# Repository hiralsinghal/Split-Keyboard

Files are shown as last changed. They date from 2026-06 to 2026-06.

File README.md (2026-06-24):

# Split-Keyboard
A split-keyboard made for ergnomic comfort. It has 42 keys, each side having 21. XIAO-nRF5280 is the MCU powering the project because of its wireless support.

## Features

- Wireless
- XIAO-nRF52840 is the MCU.
- 42 keys

## Schematic

You have draw hierarchical sheets and set the sheetname respectly whereas the sheet file should be named the same for both so that whatever symbols you place in one of them are copied into the other without you switching sheets constantly. This wouldnt impact the way footprints are imported into the PCB editor.

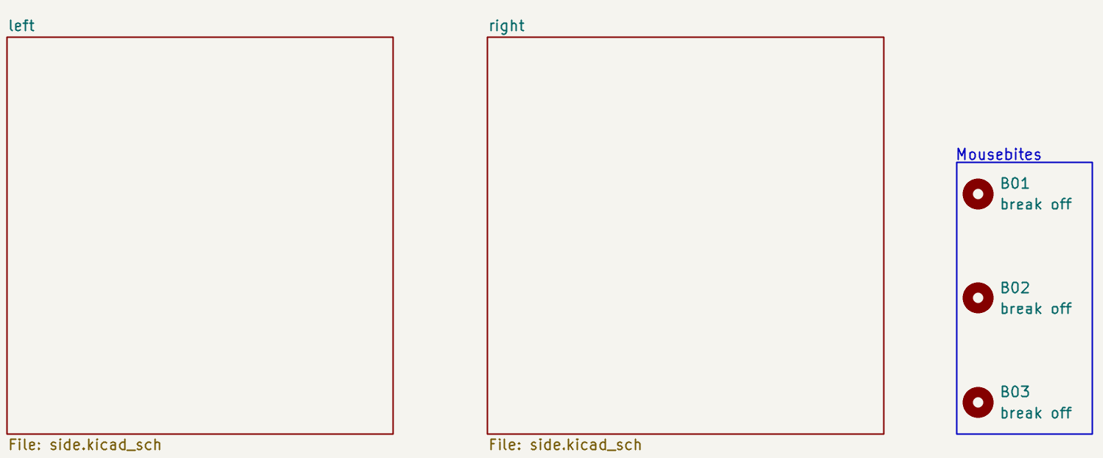
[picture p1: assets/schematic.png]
schematic


### Left Side

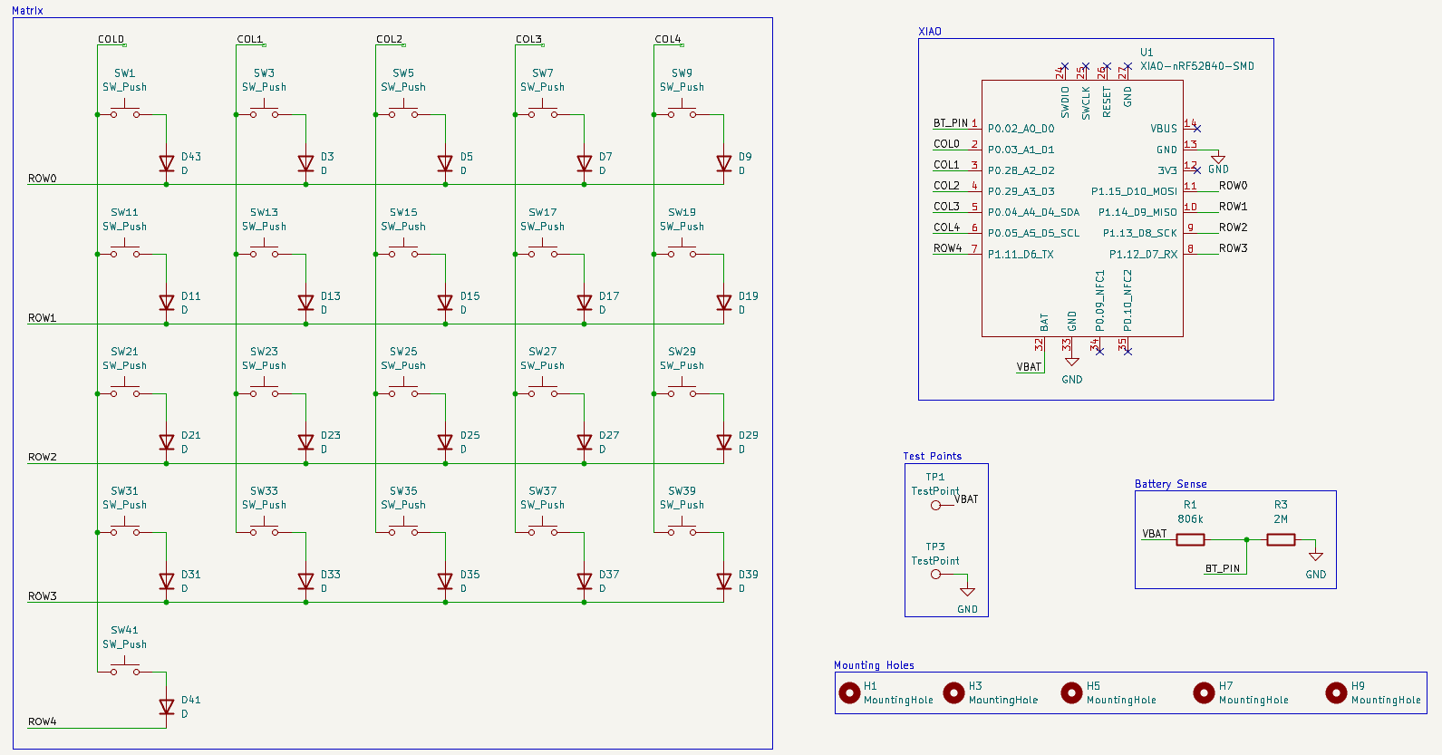
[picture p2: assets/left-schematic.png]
left side schematic


### Right Side

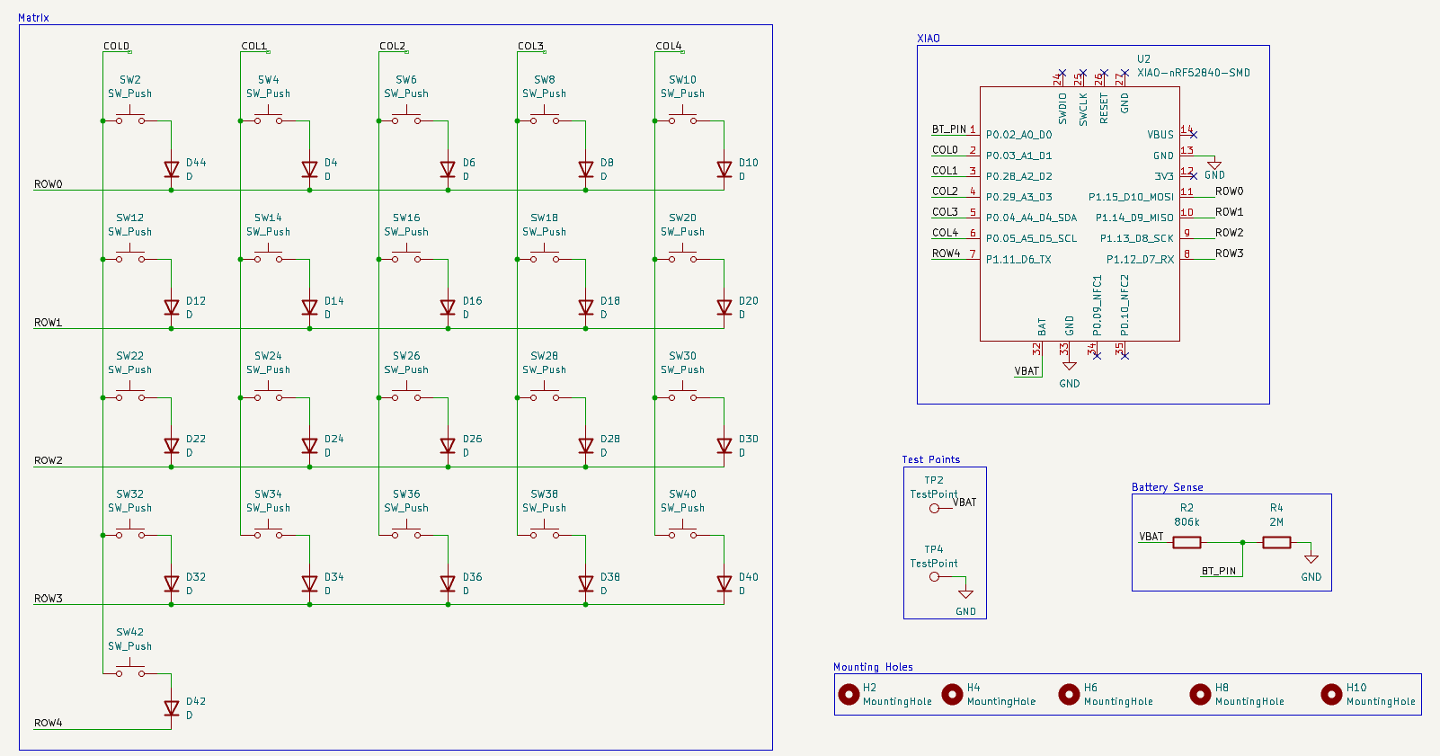
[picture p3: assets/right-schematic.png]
right side schematic


## PCB

The source files are in the PCB folder.

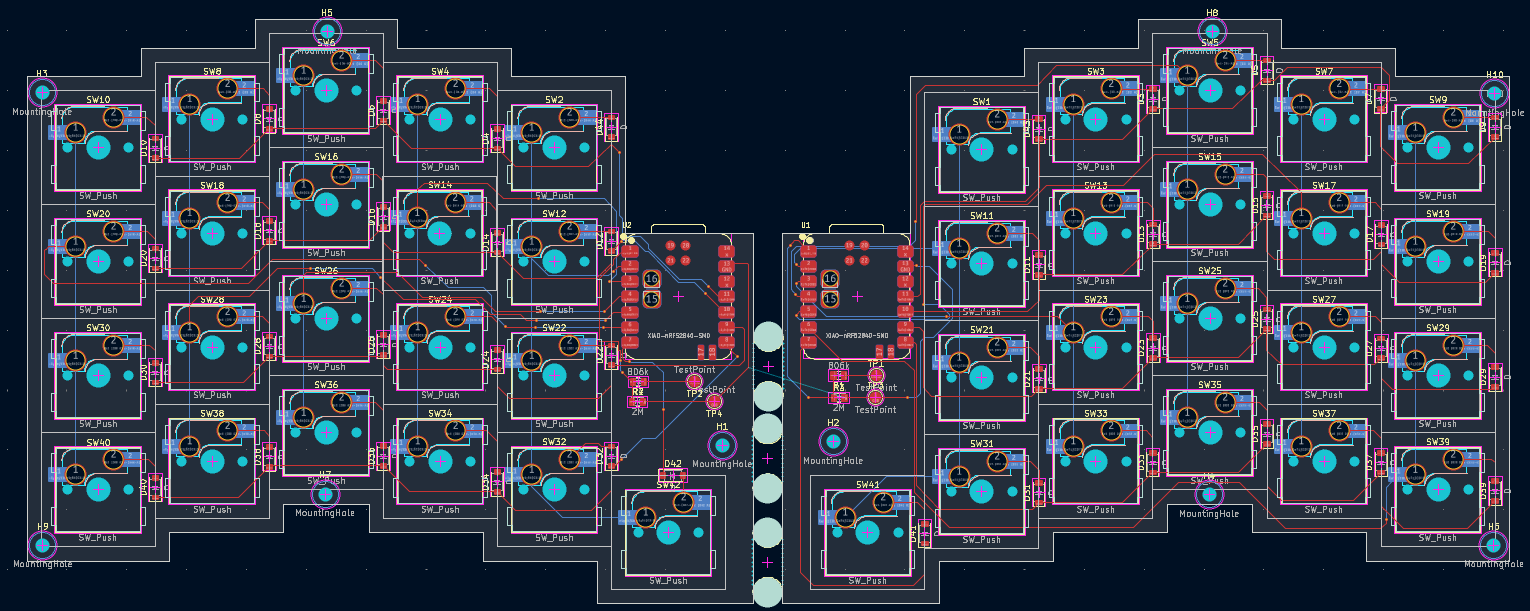
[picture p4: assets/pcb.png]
pcb


## Case

This was made in Fusion, using the PCB as reference. It has cutouts for switches, keys and XIAO ports. The source file can be found in the folder CAD.

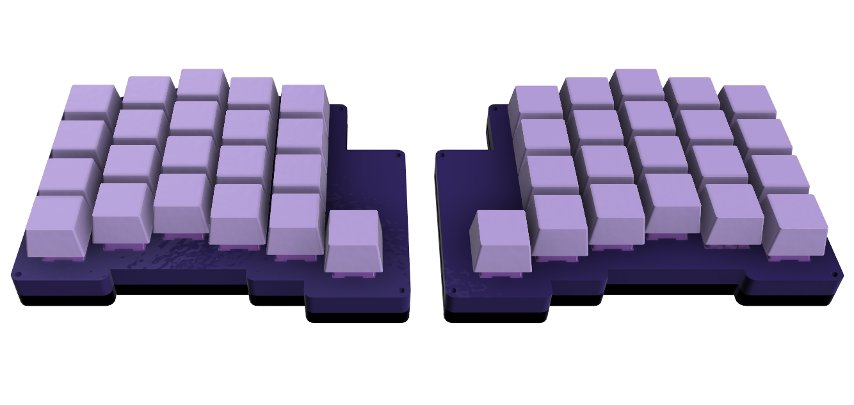
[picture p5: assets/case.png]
case


### Left

This is the case for the left side of the keyboard.

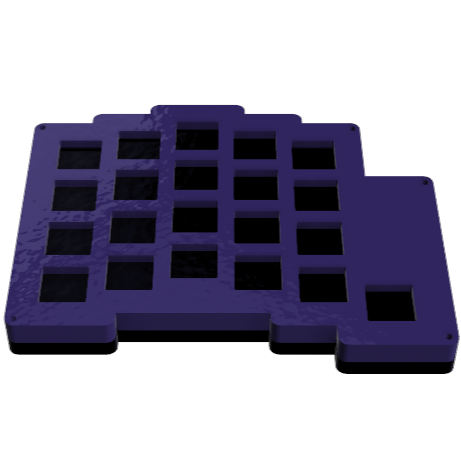
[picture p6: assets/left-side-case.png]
left-keyboard


### Right

This is the case for the right side of the keyboard.

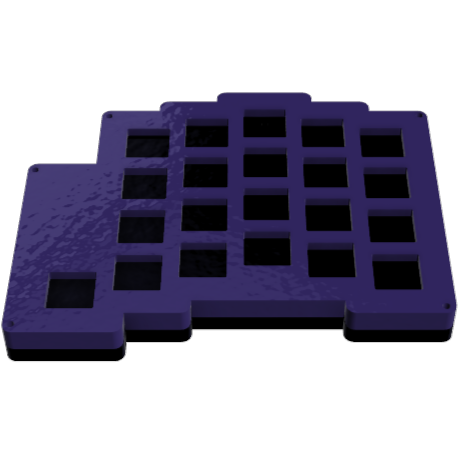
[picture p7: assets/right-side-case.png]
right-keyboard


## Firmware

It uses ZMK firmware because of its support for split keyboards. Each controller runs their own firmware but they make it work as a single device. The files are in the firmware folder.

## BOM

| Item | Description | Quantity | Unit Price ($) | Total Price ($) | URL |
| --- | --- |---| --- |--- | --- |
| PCB | PCB | 5 | 3.32 | 16.6 | |
| Seeed Studio XIAO BLE nRF52840 |MCU |2|12.2|24.4|https://robu.in/product/seeed-studio-xiao-ble-nrf52840/ |
| Akko V3 Lavender Purple Pro Switch (Pack of 45)| Keyboard Switches | 1 | 11.65 | 11.65 | https://stackskb.com/store/akko-v3-lavender-purple-pro-switch-pack-of-45/ |
| Veekos Gradient Keycaps (Cherry Profile) (135 keys)| Keycaps | 1 | 13.77 | 13.77 | https://stackskb.com/store/veekos-gradient-keycaps-cherry-profile-135-keys/?attribute_pa_colour=black |
| 1N5819 1W Diode | Diode | 42 | 0.027 | 1.13 | https://robu.in/product/1n5819-1w-diode-pack-of-30/ |
| 0805S8F1005T5E-Royal Ohm-10M 1% 0805 SMD Resistor | Resistor | 4 | 0.0086 | 0.034 | https://robu.in/product/0805s8f1005t5e-royal-ohm-10m-1-0805-smd-resistor/
| Total | | | |67.584| |

## Zine

This was made in Figma. I enjoyed making it kinda.

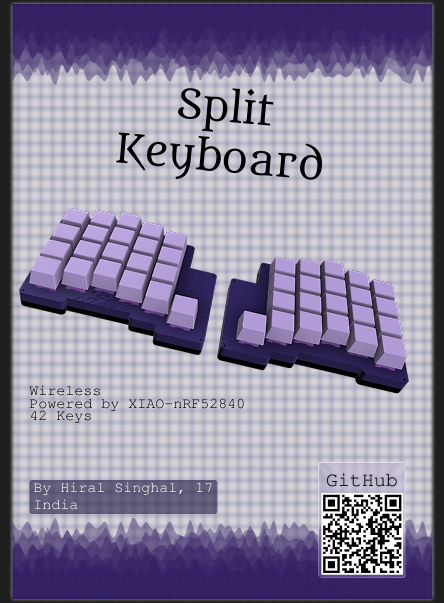
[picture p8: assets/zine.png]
zine


## Why did I make it?

I made it cause it seemed like a cool project. The routing was tough ngl. Each footprint alligned differently and so many switches and diodes. Its like each project is improving my skills consistently. I now know how to route better (kinda) This was made for [Fallout](fallout.hackclub.com).

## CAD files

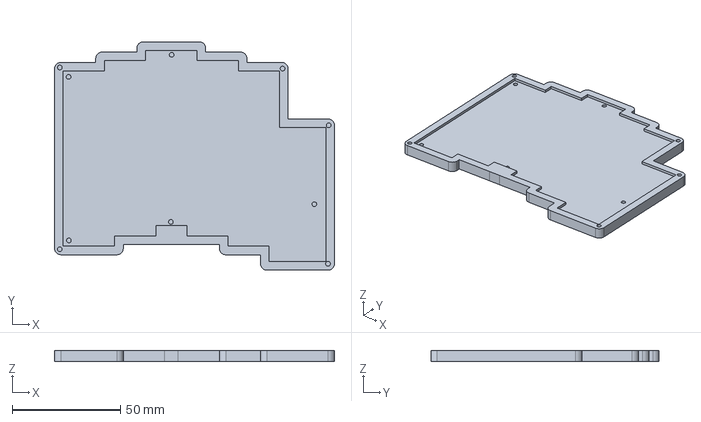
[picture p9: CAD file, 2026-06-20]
CAD/left-bottom-case.step
129.4 x 105.6 x 5.30 mm

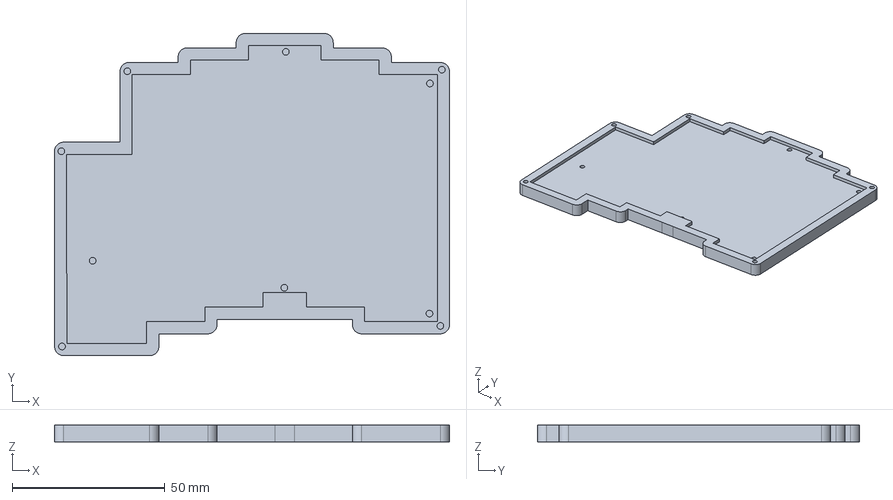
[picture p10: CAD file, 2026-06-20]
Production/cad/right-bottom-case.step
129.5 x 105.6 x 5.50 mm

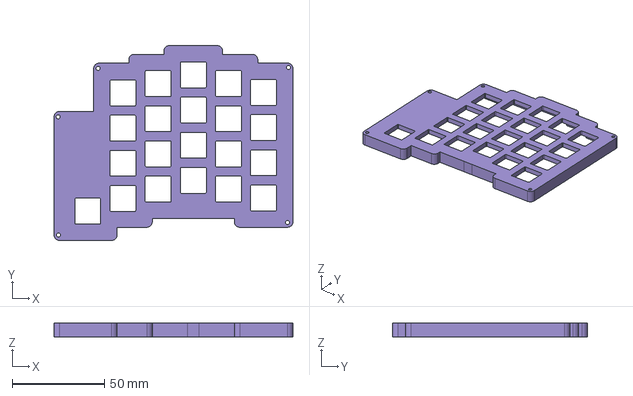
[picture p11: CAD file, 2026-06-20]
Production/cad/right-top-case.step
129.5 x 105.6 x 7.50 mm

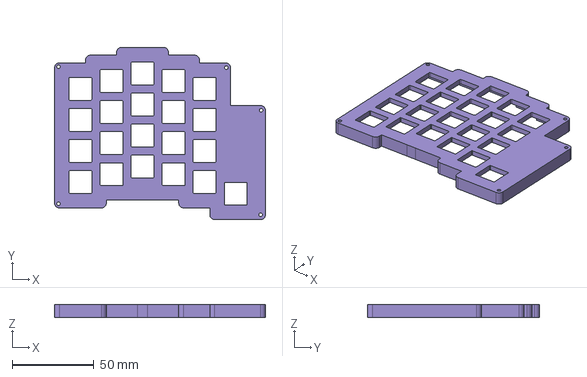
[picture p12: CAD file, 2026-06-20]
Production/cad/left-top-case.step
129.4 x 105.6 x 7.70 mm

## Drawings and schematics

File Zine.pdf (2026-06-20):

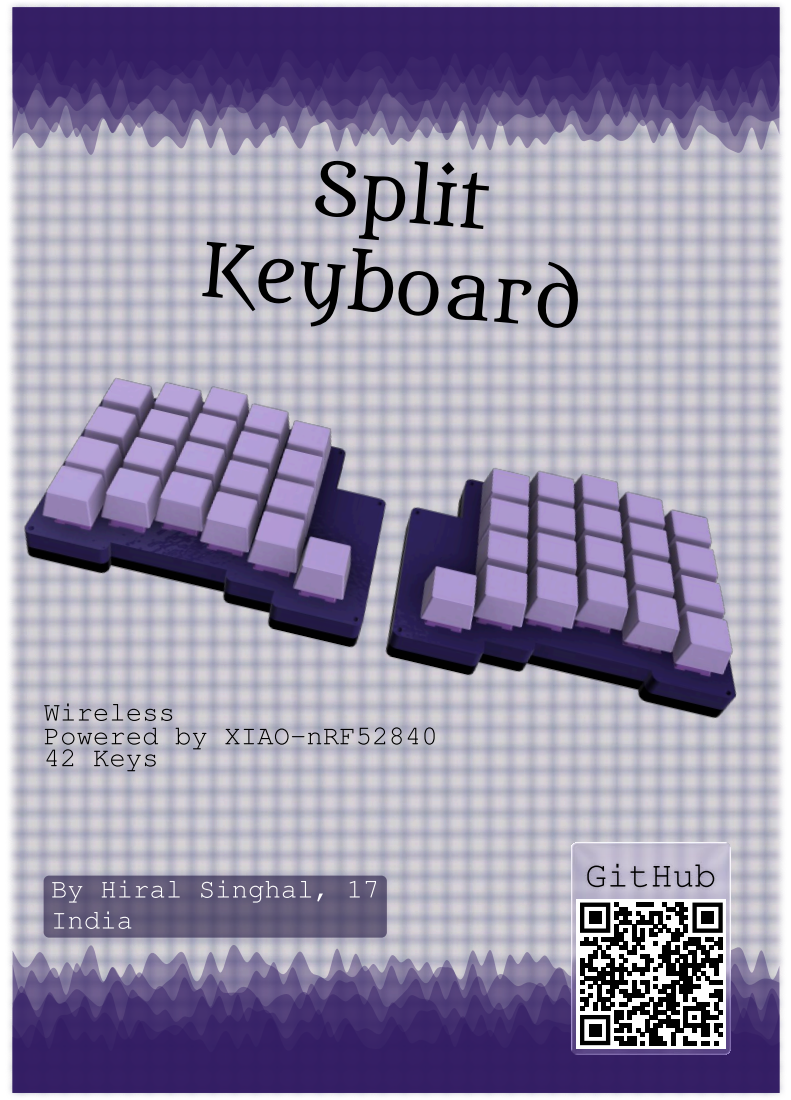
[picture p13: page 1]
Split Keyboard; GitHub

Wireless Powered by XIAO-nRF52840 42 Keys

By Hiral Singhal, 17
India

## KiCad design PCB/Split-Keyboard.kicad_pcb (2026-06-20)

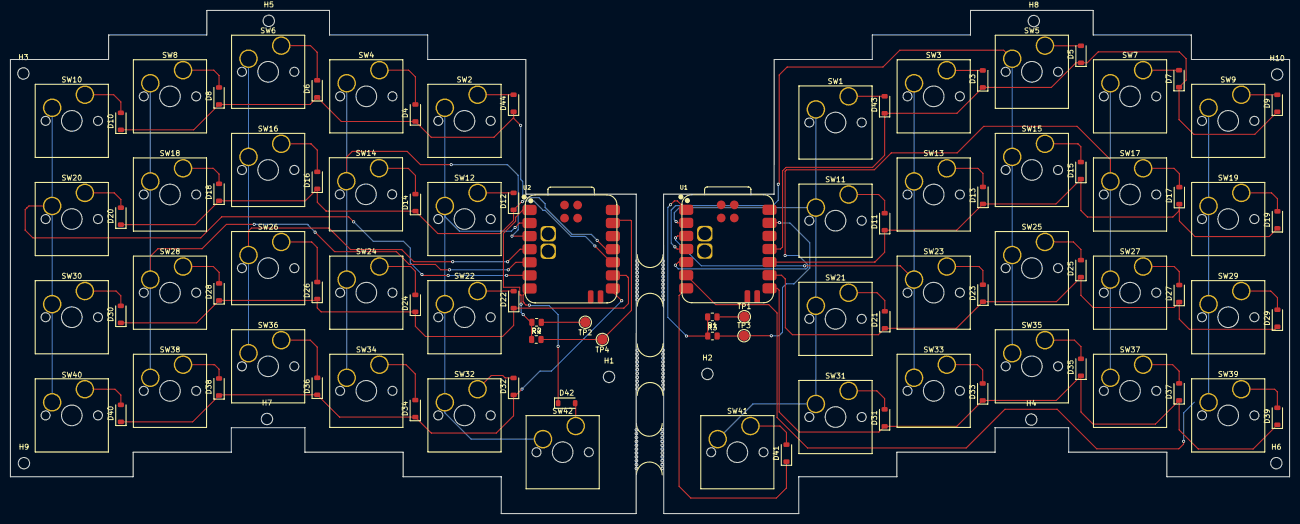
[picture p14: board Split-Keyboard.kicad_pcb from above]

Board: 2 copper layers, 248.2 x 97.6 mm, 107 parts (0 on the bottom side), 67 nets.

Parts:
B01, B02, B03: break off; mouse-bite-5mm-slot
D3, D4, D5, D6, D7, D8, D9, D10, D11, D12, D13, D14, D15, D16, D17, D18, D19, D20, D21, D22, D23, D24, D25, D26, D27, D28, D29, D30, D31, D32, D33, D34, D35, D36, D37, D38, D39, D40, D41, D42, D43, D44: D; D_SOD-123
H1, H2, H3, H4, H5, H6, H7, H8, H9, H10: MountingHole; MountingHole_2.2mm_M2
R1, R2: 806k; R_0805_2012Metric
R3, R4: 2M; R_0805_2012Metric
SW1, SW2, SW3, SW4, SW5, SW6, SW7, SW8, SW9, SW10, SW11, SW12, SW13, SW14, SW15, SW16, SW17, SW18, SW19, SW20, SW21, SW22, SW23, SW24, SW25, SW26, SW27, SW28, SW29, SW30, SW31, SW32, SW33, SW34, SW35, SW36, SW37, SW38, SW39, SW40, SW41, SW42: SW_Push; SW_Hotswap_Kailh_MX_Plated_1.00u_With_Switch
TP1, TP2, TP3, TP4: TestPoint; TestPoint_Pad_D2.0mm
U1, U2: XIAO-nRF52840-SMD; modified-XIAO-nRF52840-SMD

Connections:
/left/BT_PIN: R1.2, R3.1, U1.1 (P0.02_A0_D0)
/left/COL0: SW1.1, SW11.1, SW21.1, SW31.1, SW41.1, U1.2 (P0.03_A1_D1)
/left/COL1: SW3.1, SW13.1, SW23.1, SW33.1, U1.3 (P0.28_A2_D2)
/left/COL2: SW5.1, SW15.1, SW25.1, SW35.1, U1.4 (P0.29_A3_D3)
/left/COL3: SW7.1, SW17.1, SW27.1, SW37.1, U1.5 (P0.04_A4_D4_SDA)
/left/COL4: SW9.1, SW19.1, SW29.1, SW39.1, U1.6 (P0.05_A5_D5_SCL)
/left/ROW0: D3.1 (K), D5.1 (K), D7.1 (K), D9.1 (K), D43.1 (K), U1.11 (P1.15_D10_MOSI)
/left/ROW1: D11.1 (K), D13.1 (K), D15.1 (K), D17.1 (K), D19.1 (K), U1.10 (P1.14_D9_MISO)
/left/ROW2: D21.1 (K), D23.1 (K), D25.1 (K), D27.1 (K), D29.1 (K), U1.9 (P1.13_D8_SCK)
/left/ROW3: D31.1 (K), D33.1 (K), D35.1 (K), D37.1 (K), D39.1 (K), U1.8 (P1.12_D7_RX)
/left/ROW4: D41.1 (K), U1.7 (P1.11_D6_TX)
/left/VBAT: R1.1, TP1.1 (1_1)
/right/BT_PIN: R2.2, R4.1, U2.1 (P0.02_A0_D0)
/right/COL0: SW2.1, SW12.1, SW22.1, SW32.1, SW42.1, U2.2 (P0.03_A1_D1)
/right/COL1: SW4.1, SW14.1, SW24.1, SW34.1, U2.3 (P0.28_A2_D2)
/right/COL2: SW6.1, SW16.1, SW26.1, SW36.1, U2.4 (P0.29_A3_D3)
/right/COL3: SW8.1, SW18.1, SW28.1, SW38.1, U2.5 (P0.04_A4_D4_SDA)
/right/COL4: SW10.1, SW20.1, SW30.1, SW40.1, U2.6 (P0.05_A5_D5_SCL)
/right/ROW0: D4.1 (K), D6.1 (K), D8.1 (K), D10.1 (K), D44.1 (K), U2.11 (P1.15_D10_MOSI)
/right/ROW1: D12.1 (K), D14.1 (K), D16.1 (K), D18.1 (K), D20.1 (K), U2.10 (P1.14_D9_MISO)
/right/ROW2: D22.1 (K), D24.1 (K), D26.1 (K), D28.1 (K), D30.1 (K), U2.9 (P1.13_D8_SCK)
/right/ROW3: D32.1 (K), D34.1 (K), D36.1 (K), D38.1 (K), D40.1 (K), U2.8 (P1.12_D7_RX)
/right/ROW4: D42.1 (K), U2.7 (P1.11_D6_TX)
/right/VBAT: R2.1, TP2.1 (1_1)
GND: R3.2, R4.2, TP3.1 (1_1), TP4.1 (1_1), U1.13 (GND), U2.13 (GND)
unnamed: D3.2 (A), SW3.2
unnamed: D4.2 (A), SW4.2
unnamed: D5.2 (A), SW5.2
unnamed: D6.2 (A), SW6.2
unnamed: D7.2 (A), SW7.2
unnamed: D8.2 (A), SW8.2
unnamed: D9.2 (A), SW9.2
unnamed: D10.2 (A), SW10.2
unnamed: D11.2 (A), SW11.2
unnamed: D12.2 (A), SW12.2
unnamed: D13.2 (A), SW13.2
unnamed: D14.2 (A), SW14.2
unnamed: D15.2 (A), SW15.2
unnamed: D16.2 (A), SW16.2
unnamed: D17.2 (A), SW17.2
unnamed: D18.2 (A), SW18.2
unnamed: D19.2 (A), SW19.2
unnamed: D20.2 (A), SW20.2
unnamed: D21.2 (A), SW21.2
unnamed: D22.2 (A), SW22.2
unnamed: D23.2 (A), SW23.2
unnamed: D24.2 (A), SW24.2
unnamed: D25.2 (A), SW25.2
unnamed: D26.2 (A), SW26.2
unnamed: D27.2 (A), SW27.2
unnamed: D28.2 (A), SW28.2
unnamed: D29.2 (A), SW29.2
unnamed: D30.2 (A), SW30.2
unnamed: D31.2 (A), SW31.2
unnamed: D32.2 (A), SW32.2
unnamed: D33.2 (A), SW33.2
unnamed: D34.2 (A), SW34.2
unnamed: D35.2 (A), SW35.2
unnamed: D36.2 (A), SW36.2
unnamed: D37.2 (A), SW37.2
unnamed: D38.2 (A), SW38.2
unnamed: D39.2 (A), SW39.2
unnamed: D40.2 (A), SW40.2
unnamed: D41.2 (A), SW41.2
unnamed: D42.2 (A), SW42.2
unnamed: D43.2 (A), SW1.2
unnamed: D44.2 (A), SW2.2

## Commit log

2026-06-20 pcb stuff
    [Split-Keyboard.kicad_pcb, Split-Keyboard.kicad_sch]
2026-06-20 bom & cad things
    [BOM.csv, left-bottom-case.step, left-top-case.step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]
2026-06-20 bom updates
    [BOM.csv]
2026-06-24 fix case img
2026-06-24 update bom
    [BOM.csv]
2026-06-24 add case step
